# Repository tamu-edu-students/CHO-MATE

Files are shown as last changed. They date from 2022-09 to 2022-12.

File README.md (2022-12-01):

<p align="center">
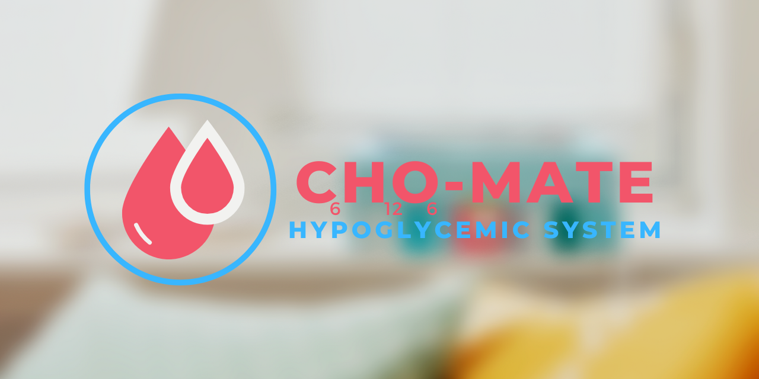
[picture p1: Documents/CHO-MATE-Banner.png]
  
</p>

# CHO-MATE

This is the CHO-MATE Hypoglycemic Center Project for ECEN 403 and ECEN 404 at Texas A&M University.

## The Problem
In the U.S. Alone over 10% of the population suffers from Diabetes. Type 1 diabetes can require a person to monitor their blood sugar level 4-10 times a day and intake carbohydrates if their blood sugar is low. This can become a guess and check game where the person is not able to consistently and accurately dose themselves, and can lead to detrimental effects on quality of life.

## Our Solution
Our device shall be a tool for those who suffer from Hypoglycemia in order to take preventative action to dose the user when their blood sugar begins to drop below acceptable conditions. We hope to provide a smooth running and adaptive source of accurate sugar dispensing to our consumers. Accomplishing both a maintenance efficient and emergency equipped system to ease some of the stress that the user must deal with on a day to day basis.

## Application Setup
To setup your own version of the application, download the [Expo Go](https://expo.dev/client) on your phone application to get started.

1. Clone the repo to your computer - `git clone https://tamu-edu-students/CHO-MATE.git`
2. Ensure NodeJS is installed on your system - You can download NodeJS [here](https://nodejs.org/en/download/)
3. Run `npm install` in the Application directory
4. Run `npm run dev` to start a development server, and **scan the QR code using your phone**. This will open Expo Go.
5. You're all set!

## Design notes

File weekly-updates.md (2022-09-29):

# CHO-MATE-Updates
## 9/29/2022
**Holden (Power Supply)** - Power Supply: Finalized validation, Began housing design in cad, Integrated with microcontroller to check everything works,
**Kelton (Application)** - Working on notification testing, adding more app screens for more user information
**Abhi (Microcontroller)** - Started CAD Design, measuring each component for input into AutoCAD

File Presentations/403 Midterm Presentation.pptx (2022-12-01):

## Team members: Kelton Chesshire, Holden Haile, Abhi Singh Sponsor: Skyelar Head TA: Sambandh Dhal


Hypoglycemic Center - C6H12O6-MATE

## Project Description - Background

In the U.S. Alone over 10% of the population suffers from Diabetes. This group has been the inspiration for many devices that make checking blood sugar simple and consistent, but none to help maintain their daily glucose intake.

## Project Description - Solution Proposal

Develop a device that can accurately dispense carbohydrates in a consistent and easily-consumable manner so that users can accurately manage their glucose levels.

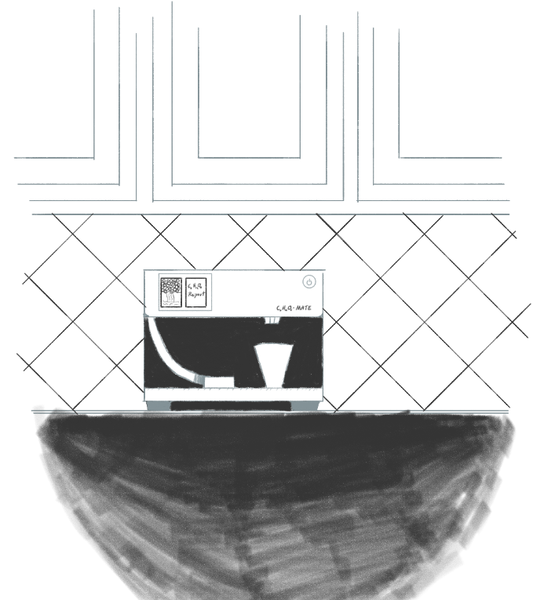
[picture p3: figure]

## Flow Chart of Subsystems

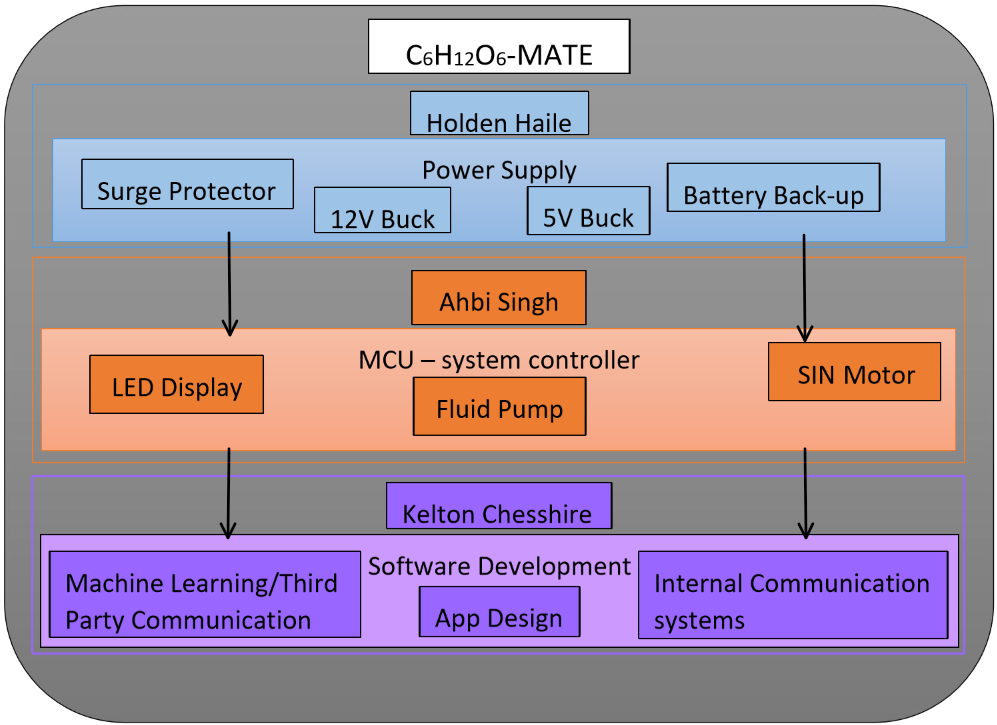
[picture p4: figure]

## Power Supply: Holden Haile

- Consists of:
  - 2 Buck converters
    - 1 x (12V, 4W) to 1 output
    - 1 x (5V, 7.5W) to 3 outputs
  - Surge Protector
  - Battery Backup

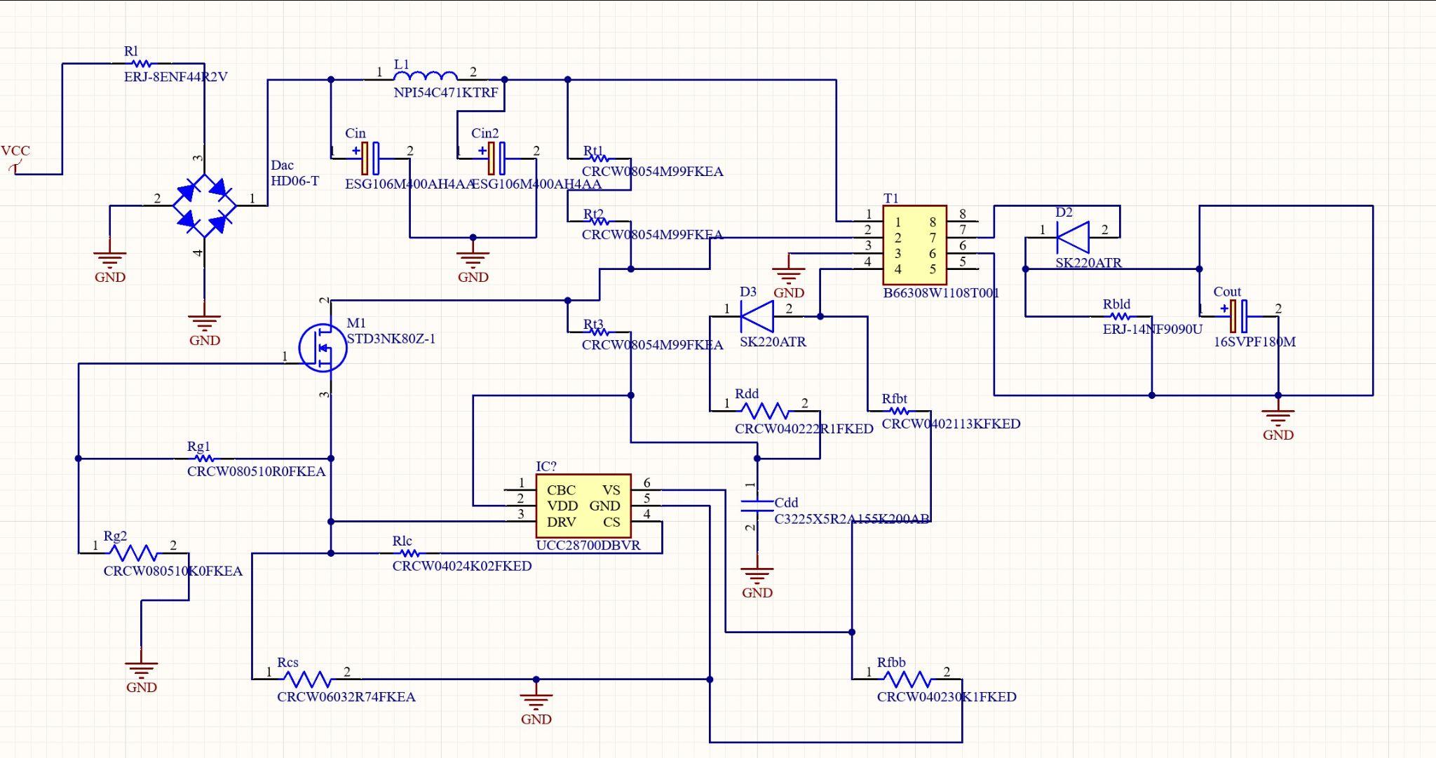
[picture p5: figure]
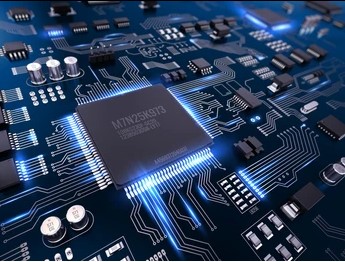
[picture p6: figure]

Image from Shudderstock.com

## Dispensing System & MCU: Abhi Singh

- Dispensing System
  - Skittle Dispenser
  - Juice Dispenser
- Onboard User Interface
  - Touch Screen Display
  - Communicates with MCU
- MCU
  - Connected via WiFi/Bluetooth to our backend which enables us to automatically dispense and alert.

## Application & Machine Learning: Kelton Chesshire

- Consists of:
  - Application Frontend & UI Design
    - Expo/Native React
  - Application Backend
    - Firebase & Express.js
  - Communication Protocols
    - WiFi Communication
    - Bluetooth Communication
  - Machine Learning

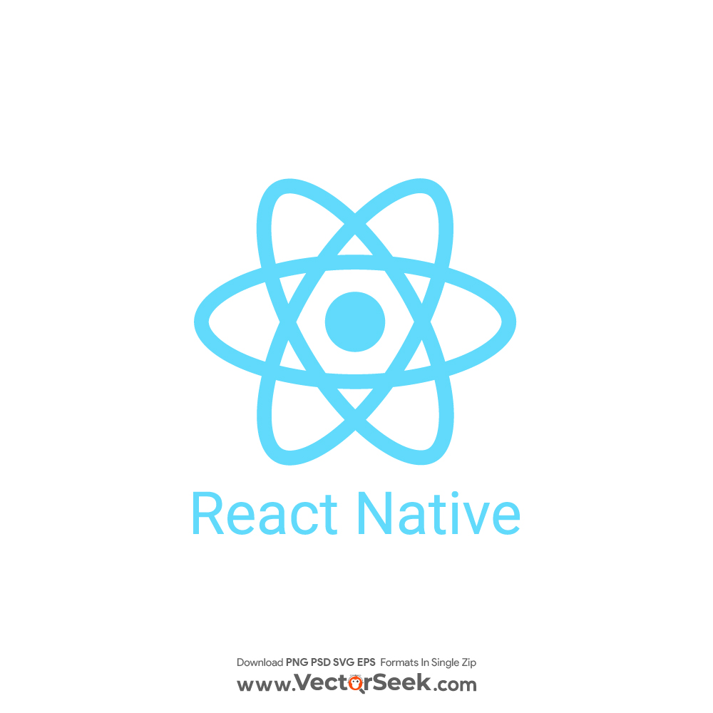
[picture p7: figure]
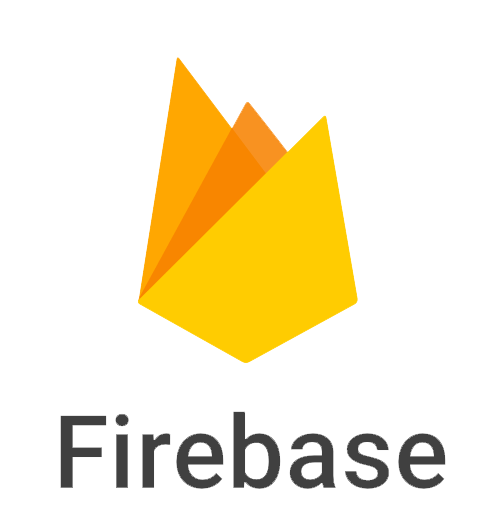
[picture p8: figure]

## Execution plan

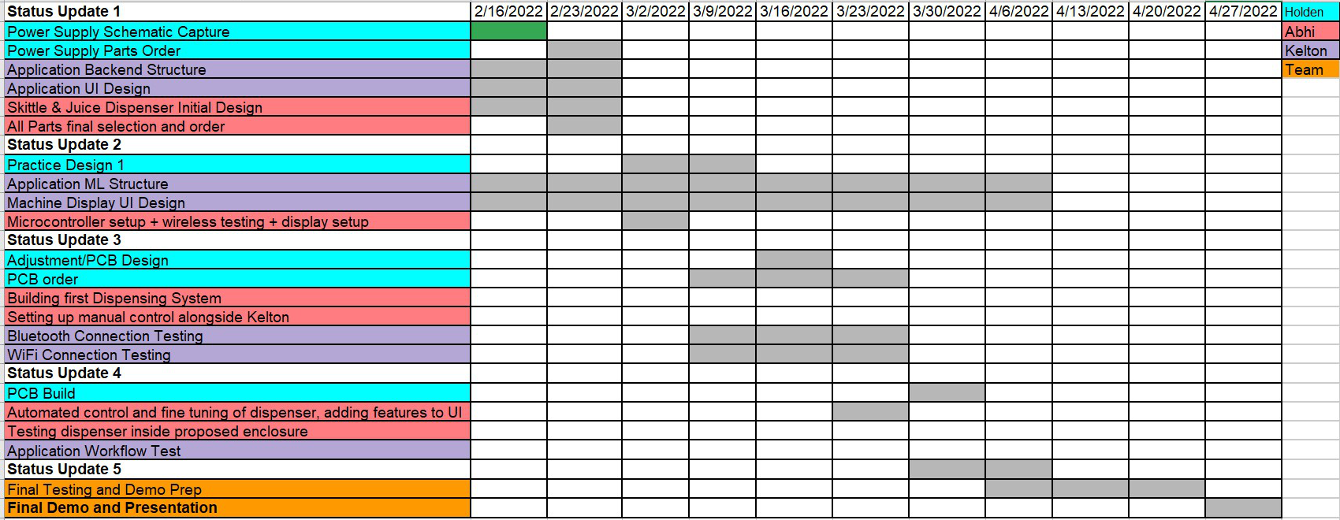
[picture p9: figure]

## Validation plan

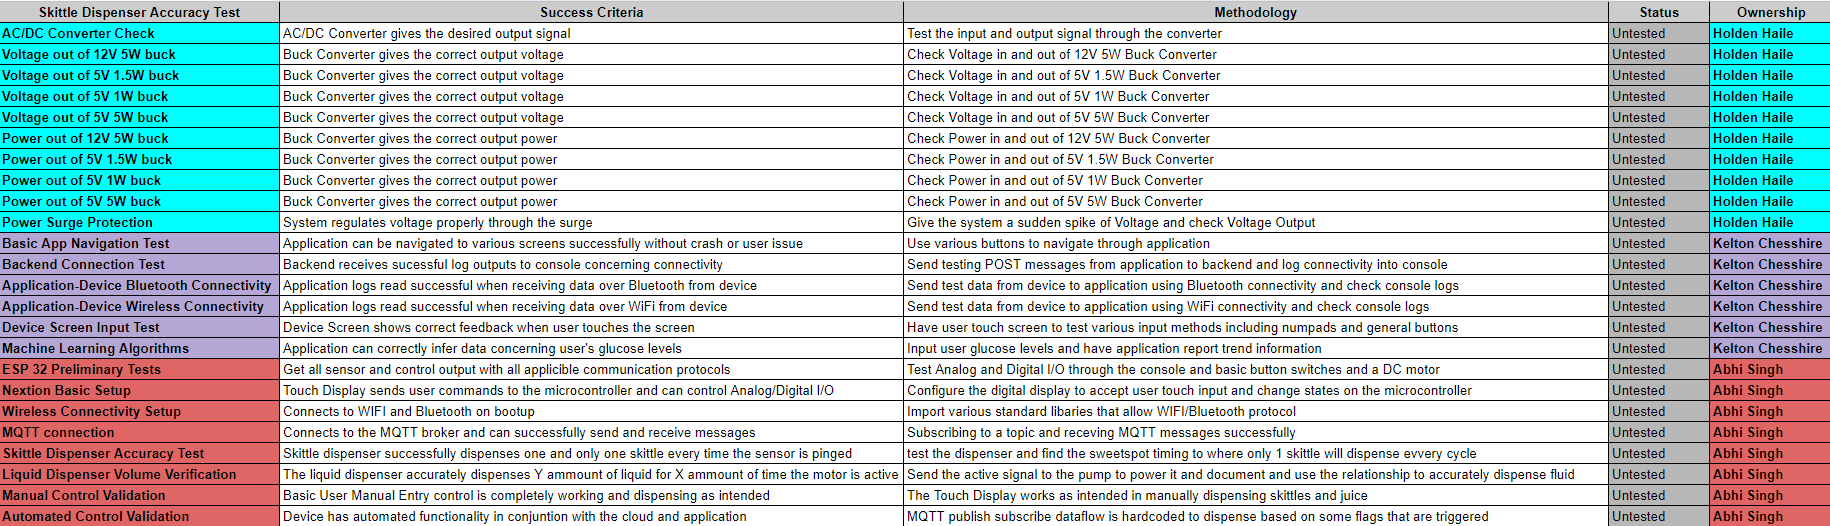
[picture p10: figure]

## Part order status

part description | Status (order approved/order placed/part received)
Raspberry Pi x 2 | Part Received
Arduino Nano | Part Received
Test Phone | Part Received
Peristaltic Liquid Pump | Not Ordered Yet

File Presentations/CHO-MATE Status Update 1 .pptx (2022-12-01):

## Bi-Weekly Update 1 Team 32: Abhi Singh, Holden Haile, Kelton Chesshire Sponsor: Skyelar Head TA: Eric Lloyd Robles


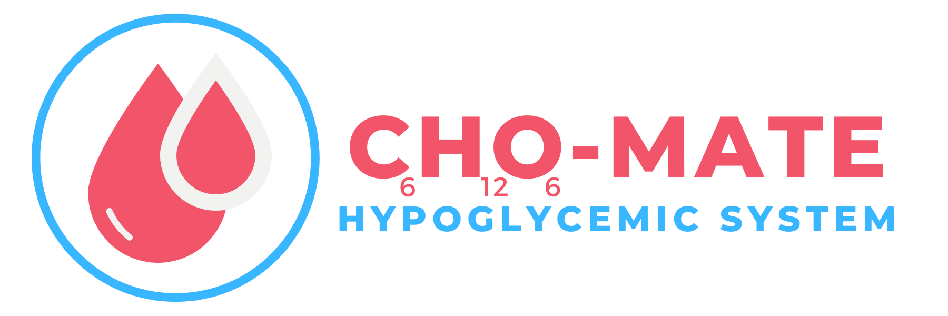
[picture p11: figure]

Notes: Michelle

## Problem Statement

In the U.S. Alone over 10% of the population suffers from Diabetes. Type 1 diabetes can require a person to monitor their blood sugar level 4-10 times a day and intake carbohydrates if their blood sugar is low. This can become a guess and check game where the person is not able to consistently and accurately dose themselves, and can lead to detrimental effects on quality of life.

## Solution Proposal

Our system will dispense carbohydrates in a consistent, accurate, and easily-consumable manner so that users have an easy way of maintaining a normal blood sugar level 24/7.


## System Overview

Power Supply

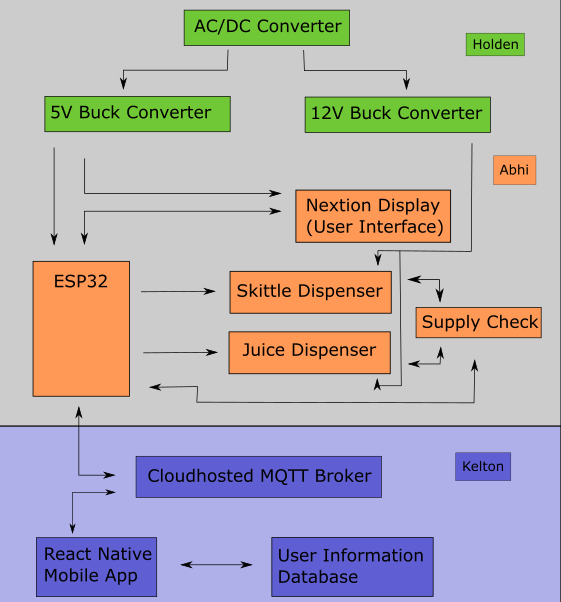
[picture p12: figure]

Dispenser

Application

## Subsystem Changes/Improvements for 404

Design Changes proposed to us by Dr. John Lusher and Subsystem Improvements that are being added for 404
Dispenser: Implementing the Skittle & Juice Stock Checker for our Dispenser, improving switching design of the dispenser, implement Nextion display
Power Supply: Swapping Voltage Regulators out and Downsizing Capacitors on Power Supply
Application: Status notifications, Glucose input, integration with Apple HealthKit and Google Fit

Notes: Eric

## Project Timeline

Discuss System Improvements

We focused on how to improve our subsystems from the good baseline from 403

Last Week

Next 2 weeks

Subsystem Improvements

Subsystem Improvements will be made and tested

10/5

Major Project Design

Design Housing and PCBs for Power Supply and Dispenser, App integration with Health Apps, HMI control implemented

11/5

Final Subsystem Integration

Dispenser and Power Supply will be installed in the housing, testing and validation of System: Dispenser powered with our Power Supply and Tested with Our App

11/16

Preparation for Final Presentation & Demo

Final Tweaks to subsystems if needed, polishing the product for presentation and testing user experience

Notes: Eric

## Power Supply Holden Haile

Accomplishments since 403 15 hrs of effort | Ongoing progress/problems and plans until the next presentation
Buck converters integrated with the MCU Discussed issues with Dr. Lusher | Implementation of re-design suggestions from Dr. Lusher Begin PCB design Begin housing design

## Power Supply Holden Haile

- 5V buck - working
- 12V buck - not providing enough power to operate at the speeds that we would like
- Revised buck design below

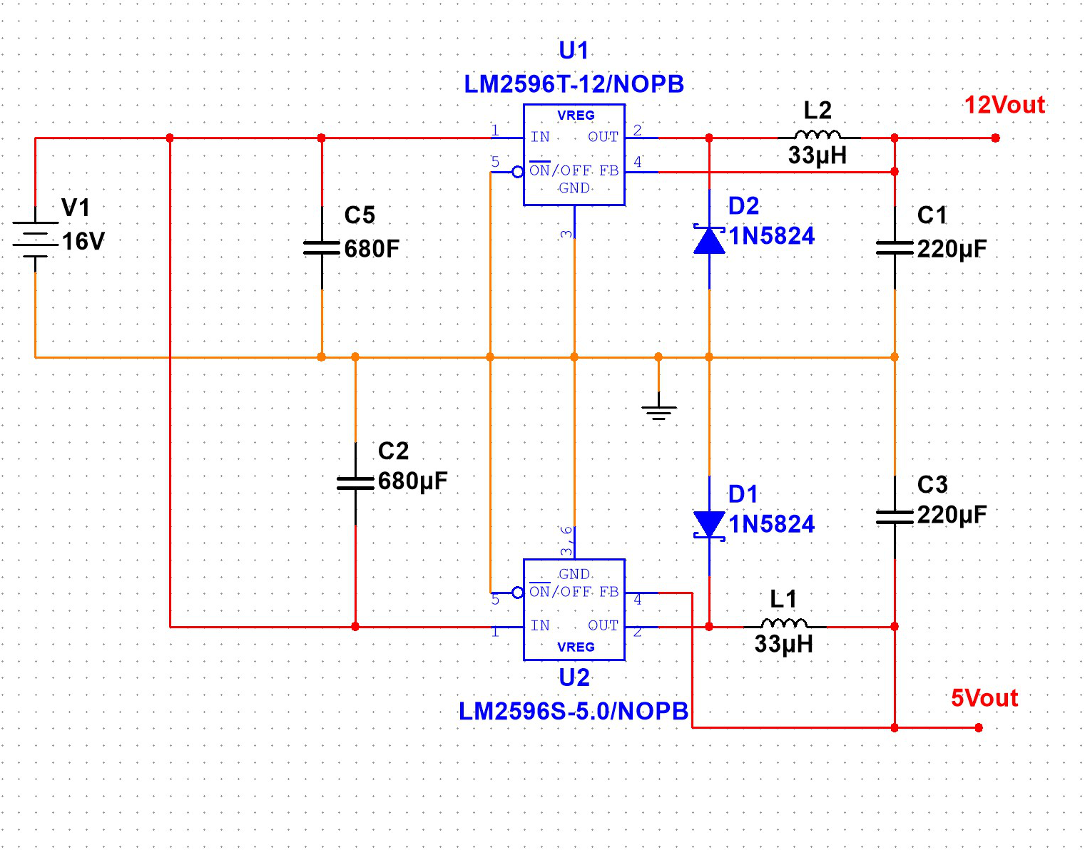
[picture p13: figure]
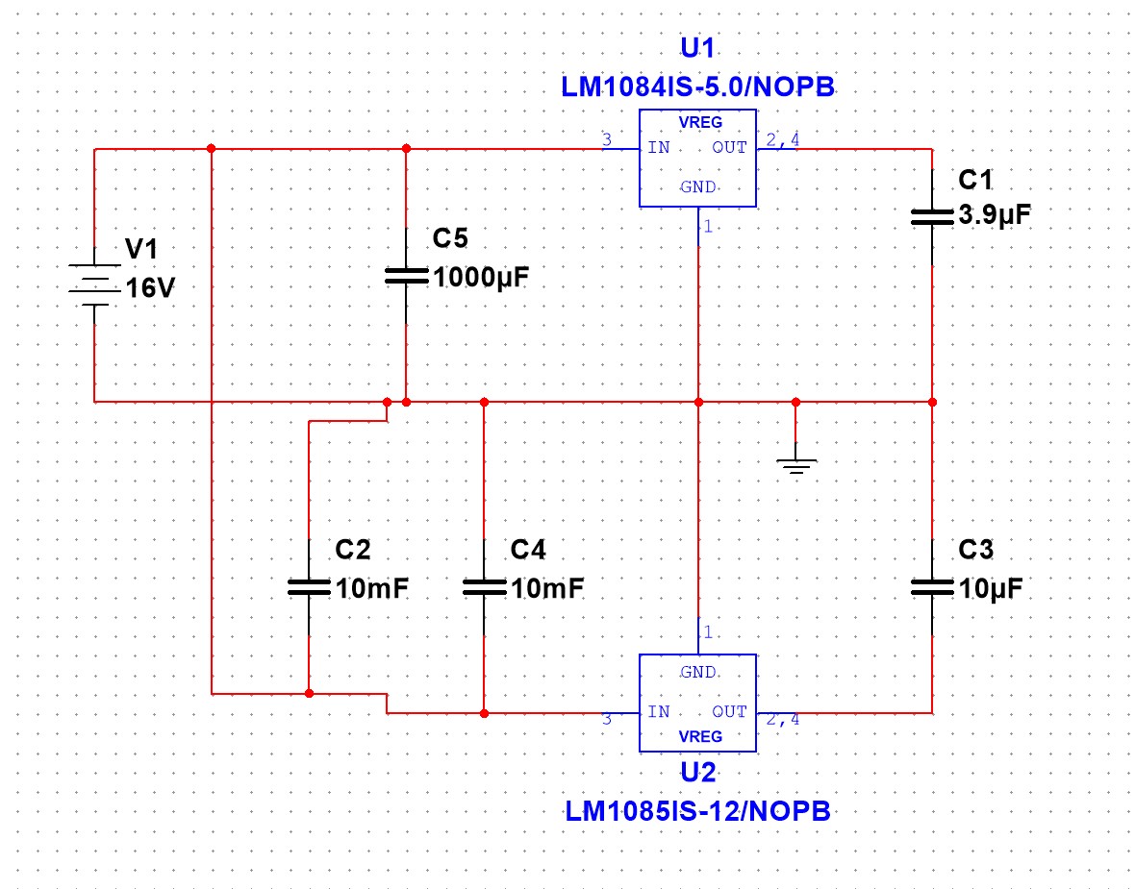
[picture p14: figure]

## Dispenser Abhi Singh

Accomplishments since 403 5 hrs of effort | Ongoing progress/problems and plans until the next presentation
Research and Sourced Sensors for Stock Checker Designed improved circuitry for dispenser using CMOS transistors instead of HV Relays | Test Ultrasonic and Pressure sensors with ESP32 Test MOSFET circuit on breadboard Implement Nextion Display (HMI)

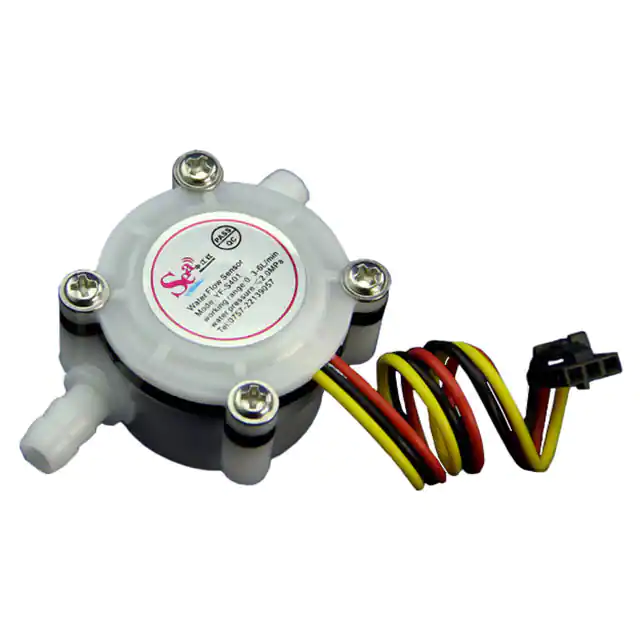
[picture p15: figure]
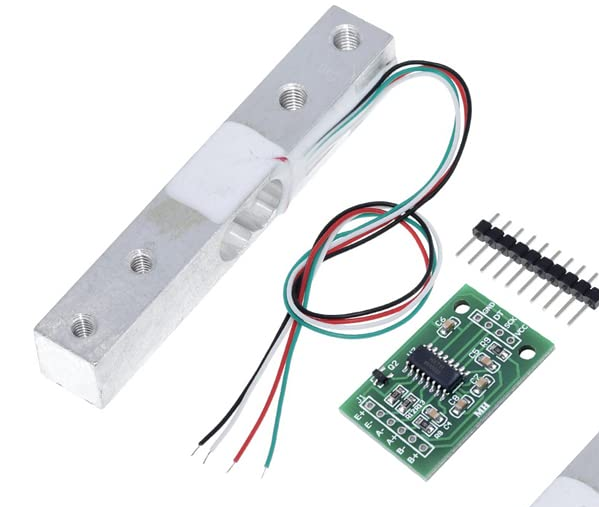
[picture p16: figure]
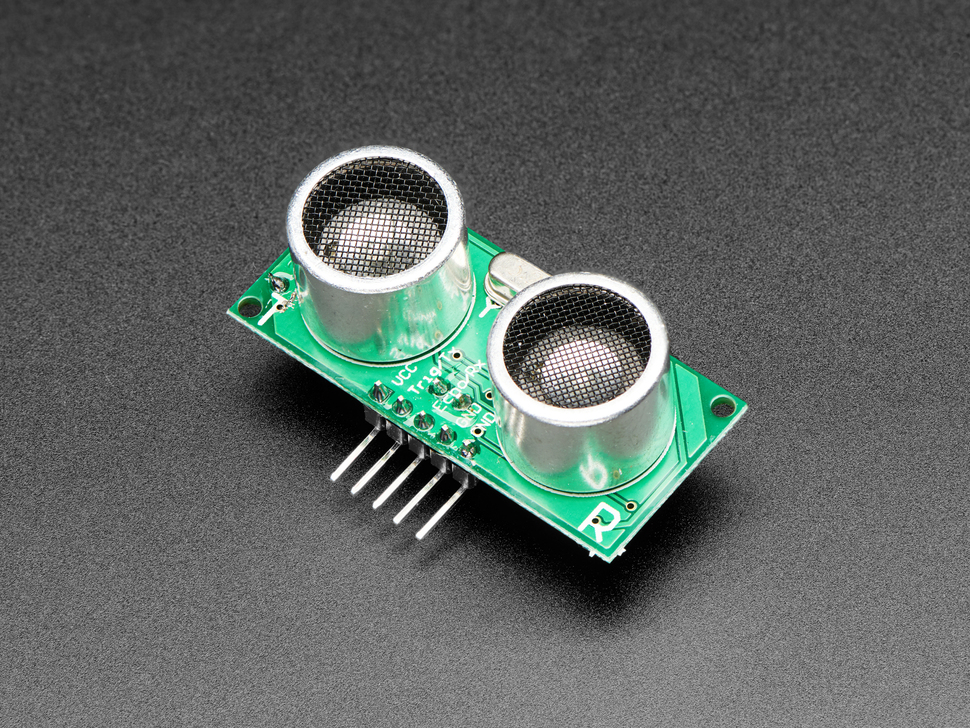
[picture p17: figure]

## Dispenser Abhi Singh

- N Channel MOSFET on the low side of the load (pump & solenoid)
- Components are here, just have to test the circuit for proof of concept
- Better alternative to what we used last semester (HV relay Optocoupler)

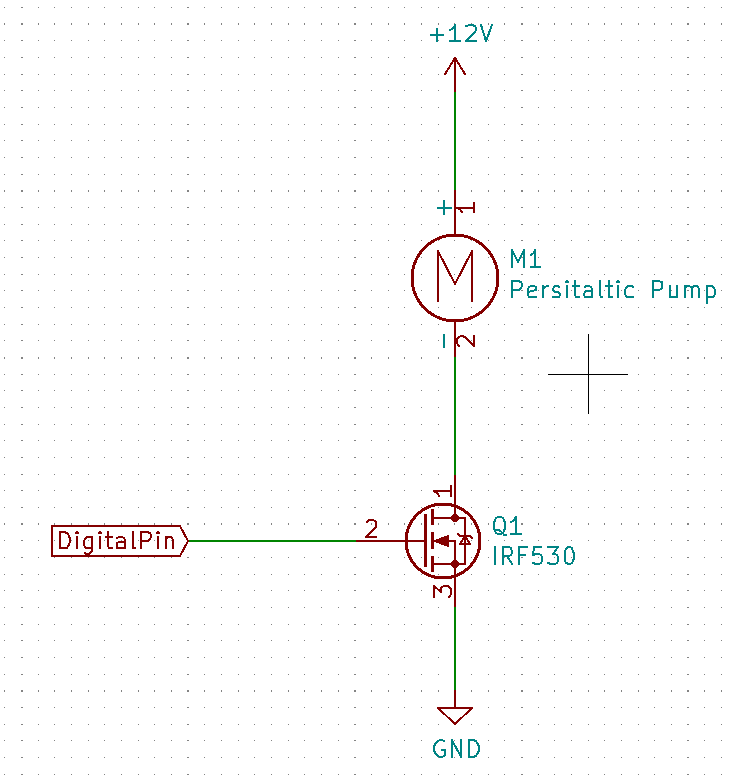
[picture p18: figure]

## Application Kelton Chesshire

Accomplishments since 403 12 hrs of effort | Ongoing progress/problems and plans until the next presentation
MQTT Communication w/ Dispenser Google Firestore Database Firebase Authentication Basic Dispense Function Previous Dispensings Screen | Dispenser Notifications Glucose Input BMI Information Work on Nextion Display with Abhi

## Application Kelton Chesshire

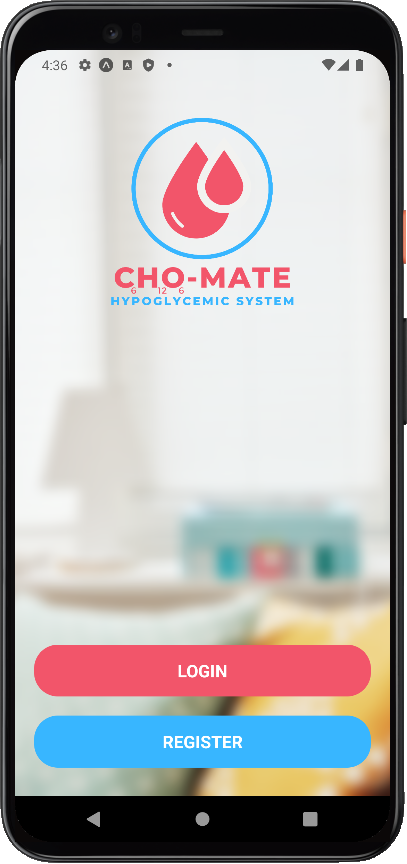
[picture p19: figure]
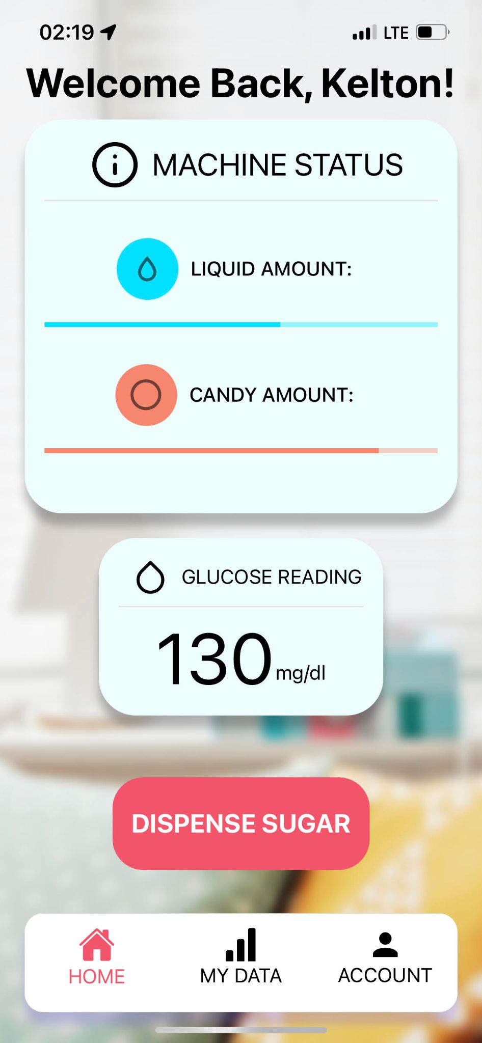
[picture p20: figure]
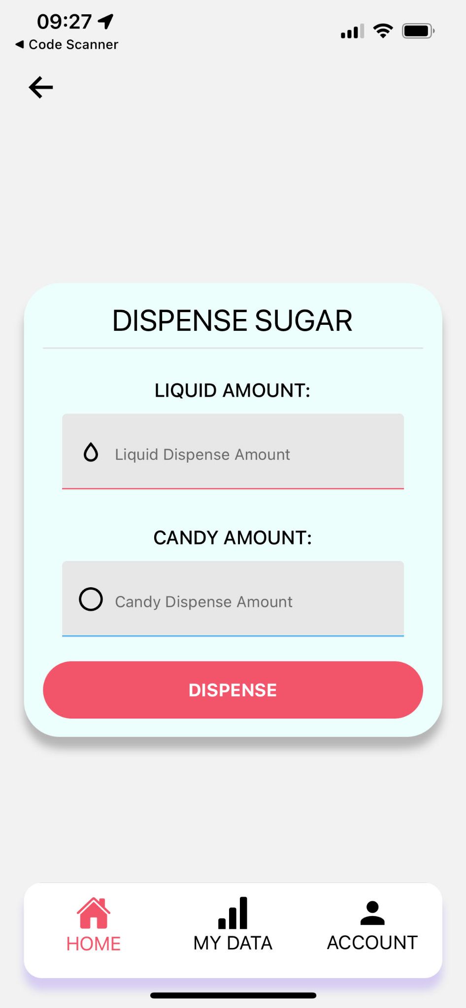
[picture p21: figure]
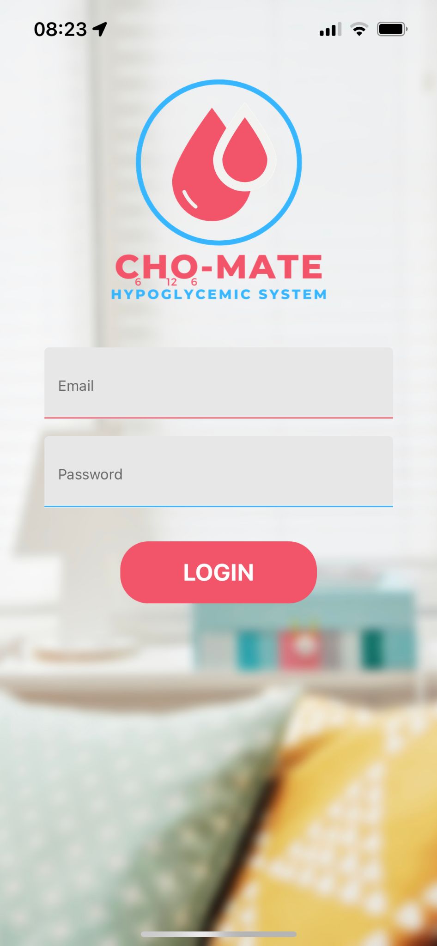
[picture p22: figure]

## Validation Plan

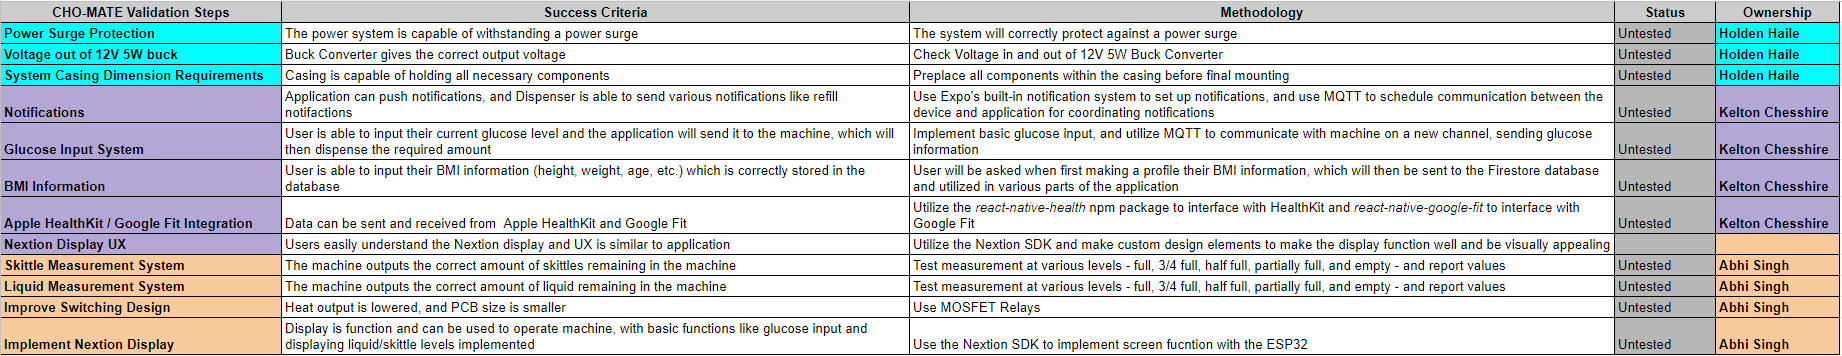
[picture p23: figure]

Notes: Michelle

## Execution Plan

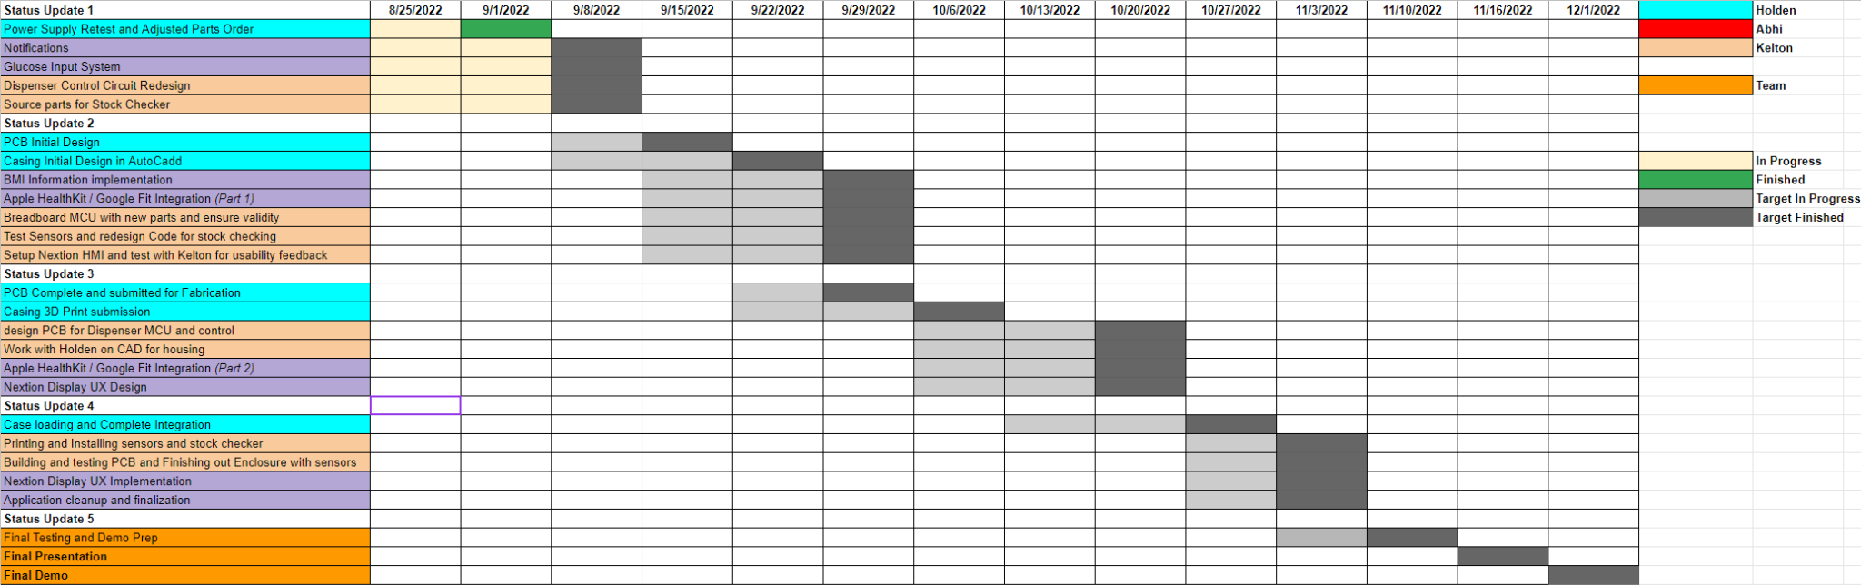
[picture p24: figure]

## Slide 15

Questions?

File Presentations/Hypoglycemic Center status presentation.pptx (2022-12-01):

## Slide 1

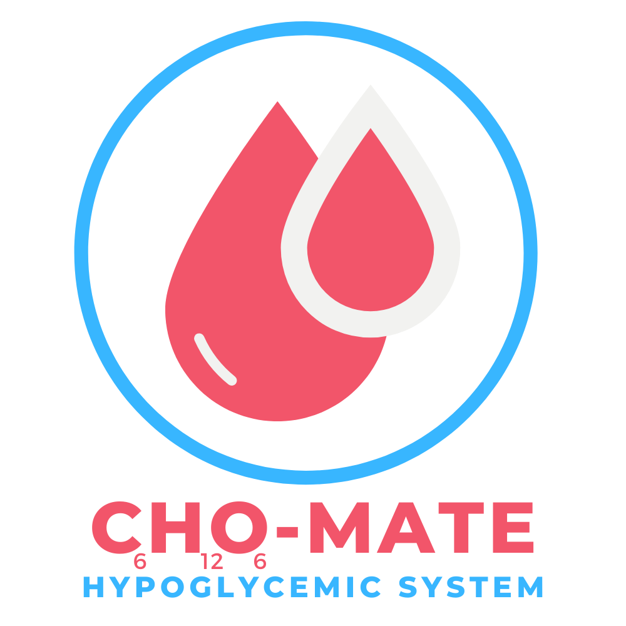
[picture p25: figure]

Sponsor:
Skyelar Head
Professor:
Dr. Kevin Nowka

Team members:
Kelton Chesshire
Holden Haile
Abhi Singh
Teaching Assistant: Sambandh Dhal

## Project Description - Background

In the U.S. Alone over 10% of the population suffers from Diabetes. This group has been the inspiration for many devices that make checking blood sugar simple and consistent, but none to help maintain their daily glucose intake.

## Project Description - Solution Proposal

Develop a device that can dispense carbs
- consistently
- accurately
- easily-consumable manner so that users can accurately manage their glucose levels.


## Flow Chart of Subsystems


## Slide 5

Power Supply Status | Buck Converter Schematic Design | Buck converter parts order | Proto Board construction | Proto Board testing | PCB Design

Microcontroller Status | Dispenser Proof of Concept & Barebones Networking | MQTT Broker setup & Testing with Dispenser | Nextion Display Interface setup | Dispenser Housing & Dispensing Accuracy | Stock Level check & MQTT multi topic messages

Software Status | Application UI Development | Application Authentication Backend

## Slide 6

Power Supply Holden Haile

Finalized Design of Both Buck Converters - 17 Hrs | Ongoing progress/problems and plans until the next presentation
adjusted designs to accommodate changes in hardware finalized designs and produced schematics ordered parts for prototype board | Awaiting parts ordered (end of week) Beginning design of PCB Practice soldering using parts ordered



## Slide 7

Dispensing System Abhi Singh

Dispenser Proof of Concept & WiFi 10 hrs | Ongoing progress/problems and plans until the next presentation
Peristaltic pump PWM testing with arduino nano and L298N motor controller esp32 network connection (Wi-Fi) achieved | setting up MQTT broker and testing dispense commands skittle dispenser test with actuator Dispenser housing design in SolidWorks


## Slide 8

Mobile Application Kelton Chesshire

Accomplishments since the last presentation 14 hrs | Ongoing progress/problems and plans until the next presentation
Basic Application UI Library UI screens Application Form Validation and Authentication | Further backend development Connection between application and Raspberry Pi testing system using MQTT Glucometer connection Push Notifications


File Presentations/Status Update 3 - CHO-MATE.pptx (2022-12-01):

## Bi-Weekly Update 3 Team 32: Abhi Singh, Holden Haile, Kelton Chesshire Sponsor: Eric Lloyd Robles TA: Eric Lloyd Robles



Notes: Michelle

## Problem Statement

In the U.S. Alone over 10% of the population suffers from Diabetes. Type 1 diabetes can require a person to monitor their blood sugar level 4-10 times a day and intake carbohydrates if their blood sugar is low. This can become a guess and check game where the person is not able to consistently and accurately dose themselves, and can lead to detrimental effects on quality of life.

## Solution Proposal

Our system will dispense carbohydrates in a consistent, accurate, and easily-consumable manner so that users have an easy way of maintaining a normal blood sugar level 24/7.


## System Overview

Power Supply


Dispenser

Application

## Subsystem Changes/Improvements since last week

Design Changes proposed to us by Dr. John Lusher and Subsystem Improvements that are being actively implemented
Dispenser: Tested Sensors, Planned Circuit Layout, Measured Dimensions for the enclosure CAD model
Power Supply: Completed system validation and verified all values in and out of the circuit
Application: Further Notification / Background Task Testing

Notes: Eric

## Project Timeline

Discuss System Improvements

We focused on how to improve our subsystems from the good baseline from 403

Last Week

Next 2 weeks

Subsystem Improvements

Subsystem Improvements will be made and tested

10/5

Major Project Design

Design Housing and PCBs for Power Supply and Dispenser, App integration with Health Apps, HMI control implemented

11/5

Final Subsystem Integration

Dispenser and Power Supply will be installed in the housing, testing and validation of System: Dispenser powered with our Power Supply and Tested with Our App

11/16

Preparation for Final Presentation & Demo

Final Tweaks to subsystems if needed, polishing the product for presentation and testing user experience

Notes: Eric

## Power Supply Holden Haile

Accomplishments since last presentation 8 hrs of effort | Ongoing progress/problems and plans until the next presentation
Validation finalized Began crash course on CAD modeling to begin enclosure design | Housing Design process Complete integration of microcontroller and power supply system

## Power Supply Holden Haile

- Power supply Validated and prepared for integration
- Housing design process started and will be worked on in the next two weeks


## Dispenser Abhi Singh

Accomplishments since Last Update 6 hrs | Ongoing progress/problems and plans until the next presentation
Designed an updated dispenser that incorporates the pressure sensor cell and improves the design to get rid of skittle jams | Design the lid for the Juice volume measurer (ultrasonic sensor 3D print both designs and begin validation Design Nextion Display pages for User Interface and test with ESP32


## Dispenser Abhi Singh


- Updated dispenser now uses a Pressure Load Cell to measure current amount of Skittles
Next Step:
- design the enclosure that will house the dispenser and the juice canister
- design the lid that will read the amount of juice in the canister

## Application Kelton Chesshire

Accomplishments since Last Update 12 hrs of effort | Ongoing progress/problems and plans until the next presentation
Notification Testing Background Task Testing | Further Notification & Background Task Testing More Information Screens

## Application Kelton Chesshire


## Validation Plan


## Execution Plan


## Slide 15

Questions?

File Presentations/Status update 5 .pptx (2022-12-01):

## Bi-Weekly Update 5 Team 32: Abhi Singh, Holden Haile, Kelton Chesshire Sponsor: Eric Lloyd Robles TA: Eric Lloyd Robles



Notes: Michelle

## Problem Statement

- In the U.S. Alone over 10% of the population suffers from Diabetes.
- Type 1 diabetes requires monitoring of blood sugar levels 4-10 times a day.
- The process can become a guess and check game with inconsistent data and little comfort for the user.


## Solution Proposal

- Dispense carbohydrates in a consistent, accurate, and easily-consumable manner.
- Provide the user with information regarding their personal blood sugar patterns.


## System Overview


Power Supply

Dispenser

Application

## Project Timeline

Discuss System Improvements

We focused on how to improve our subsystems from the good baseline from 403

Check point 1

Check point 2

Subsystem Improvements

Subsystem Improvements will be made and tested

Check point 3

Major Project Design

Design Housing and PCBs for Dispenser, App integration with Health Apps, HMI control implemented

Check point 4

Final Subsystem Integration

Dispenser and Power Supply will be installed in the housing, testing and validation of System: Dispenser powered with our Power Supply and Tested with Our App

Final Product

Preparation for Final Presentation & Demo

Final Tweaks to subsystems if needed, polishing the product for presentation and testing user experience

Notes: Eric

## Housing Design Holden Haile

Accomplishments since last presentation 17 hrs of effort | Ongoing progress/problems and plans until the next presentation
Learned the basics of solidworks from Ahbi Created first iteration of housing in solidworks | Final adjustments before submitting for 3D print

## Housing Design Holden Haile

- Housing design in cooperation with Abhi
- Housing will hold:
  - Juice & Skittle Dispensers
  - Power Supply & Surge Protector
  - Front Facing Nextion Display
  - Dispensing Tray


## Beginning Vision vs Housing Design


## Housing Design


## Dispenser Abhi Singh

Accomplishments since Last Update 7 hrs | Ongoing progress/problems and plans until the next presentation
Finished designing the PCB and validated the traces alongside the breadboarded circuit Ordered the PCB Helped Holden with the dispenser housing dimensions | Design Nextion Display pages for user interface using Kelton’s Canva Designs and test with ESP32 Build the dispenser using completed 3D prints and our various electronic components

## Dispenser Abhi Singh

- PCB is designed, reviewed, and ordered
- Currently running prints for completed CAD parts


## Application Kelton Chesshire

Accomplishments since Last Update 9 hrs of effort | Ongoing progress/problems and plans until the next presentation
Backend deployment and setup Notification Service deployment | More information screens Nextion Display UI

## Application Kelton Chesshire

BACKEND:
Sends “STOCK” through MQTT to all CHO-MATE devices

CHO-MATE:
Sends back Liquid and Skittle amounts

BACKEND:
If below 20%, send low notification to Application


## Validation Plan


## Execution Plan


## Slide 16

Questions?

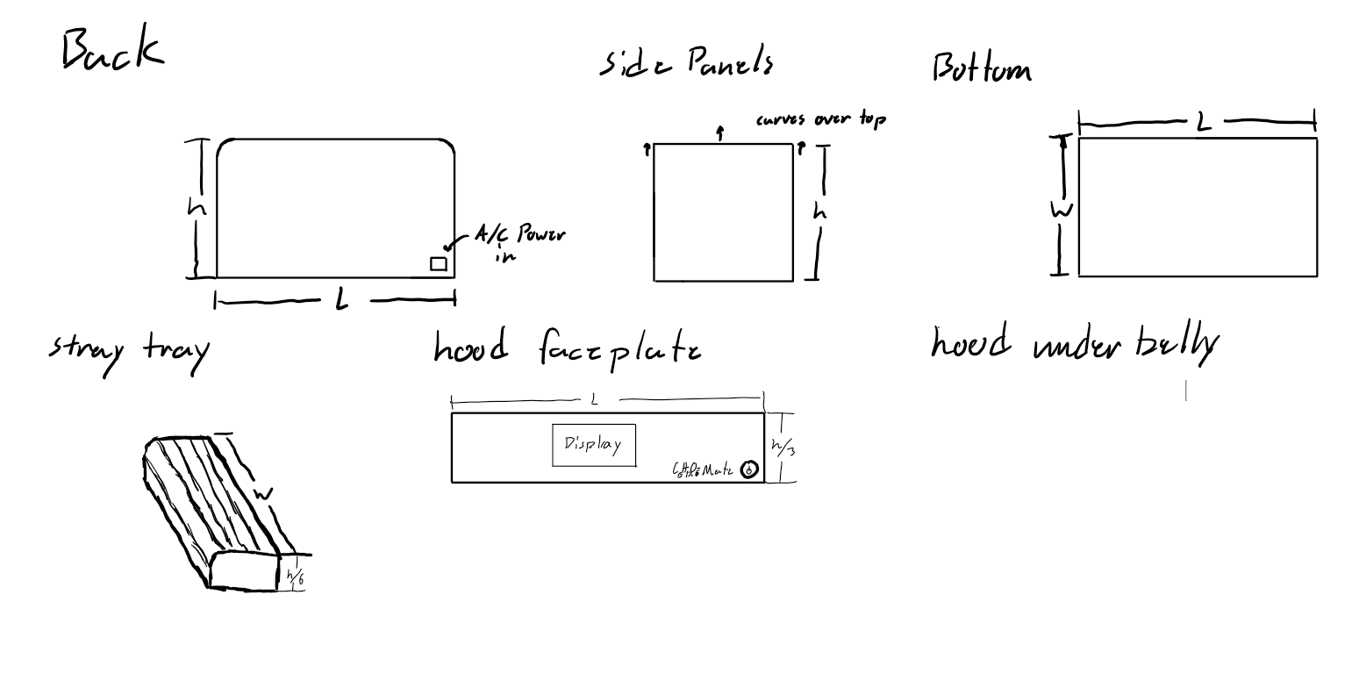
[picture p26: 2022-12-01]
Documents/Housing sketches.png

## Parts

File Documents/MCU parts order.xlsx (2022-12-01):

Part Name | Link | Unit Price | Quantity | Team Member | Order Status | Net Cost
ESP32 | https://www.amazon.com/gp/product/B0718T232Z/ref=ox_sc_act_title_3?smid=A30QSGOJR8LMXA&psc=1 | $10.99 | 1 | Abhi | Sent to Business Office | $11
Peristaltic Pump | https://www.amazon.com/gp/product/B09MS6C91D/ref=ox_sc_act_title_1?smid=A13IDDRW9YEST&psc=1 | $31 | 1 | Abhi | Sent to Business Office | $31
Nextion 5'' Enhanced | https://itead.cc/product/nx8048k050-nextion-5-0-enhanced-series-hmi-touch-display/ | $69.90 | 1 | Abhi | Sent to Business Office | $69.90 | Total
L298N motor controller | https://www.amazon.com/Qunqi-Controller-Module-Stepper-Arduino/dp/B014KMHSW6 | $6.99 | 1 | Abhi | Sent to Business Office | 6.99 | 118.89
404 Parts
flow meter | https://www.digikey.com/en/products/detail/seeed-technology-co.,-ltd/314150001/5488169 | $9.50 | 1 | Abhi | sent
weight sensor | https://www.amazon.com/Digital-Weighing-Arduino-Portable-Electronic/dp/B09K7G3477?s=industrial | 8 | 2 | Abhi | sent
ultrasonic sensor | https://www.adafruit.com/product/4019 | 6.95 | 1 | Abhi | sent

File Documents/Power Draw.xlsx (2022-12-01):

Component | Link | Voltage (Volts) | Needs Regulation? (Y/N) | Max Rated Power Draw (Watts) | current
12V supply
Peristaltic Pump | https://www.adafruit.com/product/1150#technical-details | 12V | Y | 24W | 2A
10mm P+P Solenoid | https://www.amazon.com/Kiro-Seeu-JF-0530B-Electromagnet-Keepping/dp/B09B2772PX | 12V | Y | 7.2W | 0.6
 |  |  |  |  | total current
 |  |  | 12V Power Draw Max | 31.2W | 2.6A
5V supply
ESP32 | https://www.amazon.com/gp/product/B0718T232Z/ref=ox_sc_act_title_3?smid=A30QSGOJR8LMXA&psc=1 | 5V | Y | 1.5W | .3A
Nextion Display 5'' | https://itead.cc/product/nx8048k050-nextion-5-0-enhanced-series-hmi-touch-display/ | 5V | Y | 5W | 0.41A
N channel MOSFETS | https://www.amazon.com/HiLetgo-Channel-optocoupler-Support-Trigger/dp/B00LW15A4W | 5V | Y | 1W
 |  |  |  |  | total current
 |  |  | 5V Power Draw Max | 7.5W | 1.5A

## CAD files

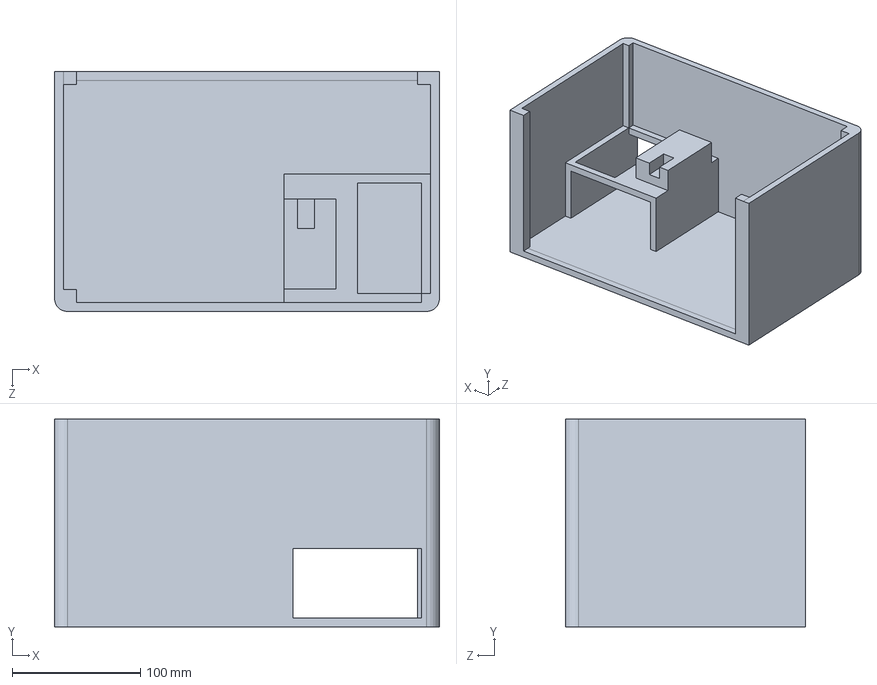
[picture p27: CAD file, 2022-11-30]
SolidWorks/Back_updated_full.SLDPRT
300.0 x 162.0 x 187.0 mm

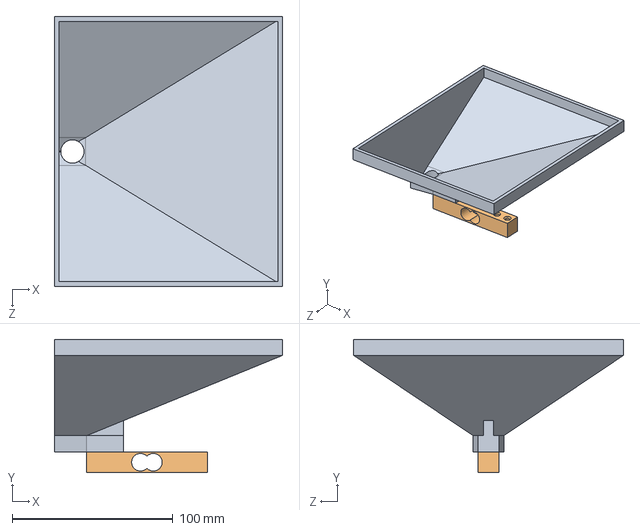
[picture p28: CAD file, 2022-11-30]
SolidWorks/skittledispenser.SLDASM
142.0 x 83.0 x 168.0 mm
updated_funnel
pressure_sensor

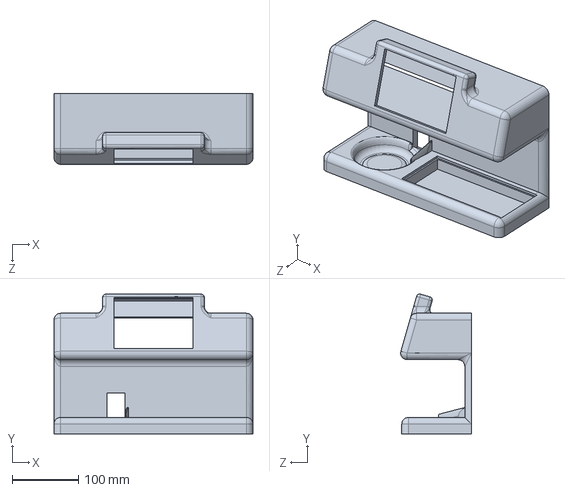
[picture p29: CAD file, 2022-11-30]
SolidWorks/Assem1.SLDASM
300.0 x 210.9 x 106.7 mm

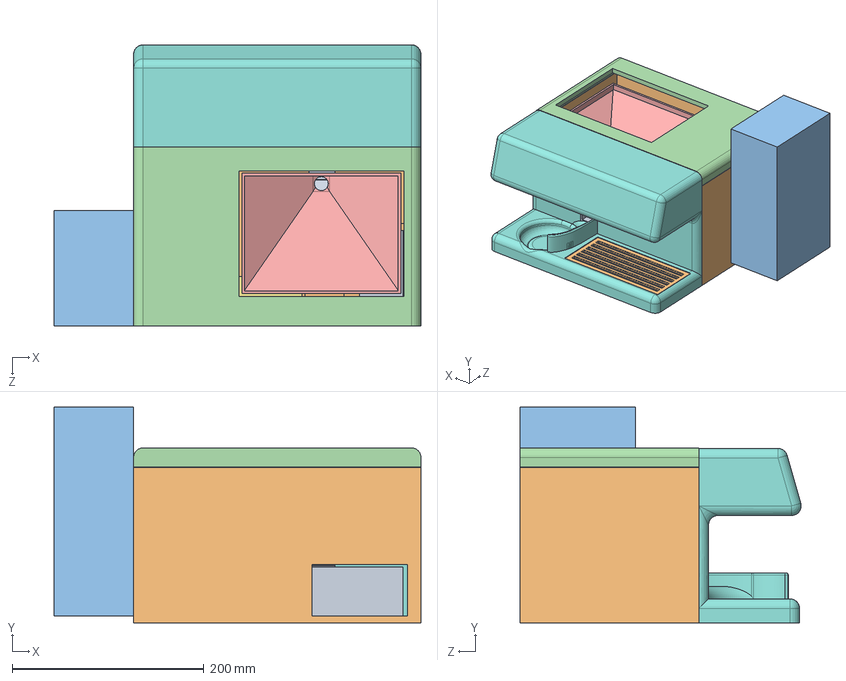
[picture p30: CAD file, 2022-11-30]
SolidWorks/Assembly.SLDASM
383.0 x 225.0 x 293.7 mm
Surge Protector
Back_updated
Water bottle
Top
updated_funnel
pressure_sensor
psu
Tray
Skittle Ramp
Tray insert

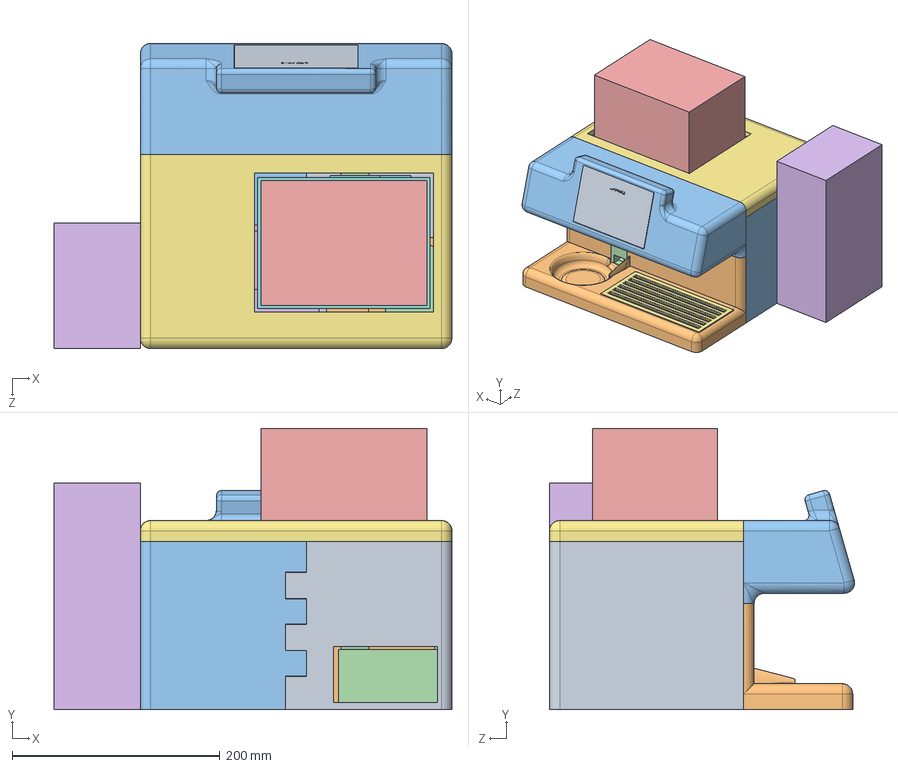
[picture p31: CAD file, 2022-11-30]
SolidWorks/V1_Final_Assembly.SLDASM
383.0 x 270.7 x 293.7 mm
Back_updated_left
power_supply_housing
back_updated_right
Surge Protector
pressure_sensor
psu
Top
dispenserv3
Nextion 5inch display
Tray_bottom
Tray_Top
Skittle ramp version 2
Skittle_container
Water bottle
Tray insert

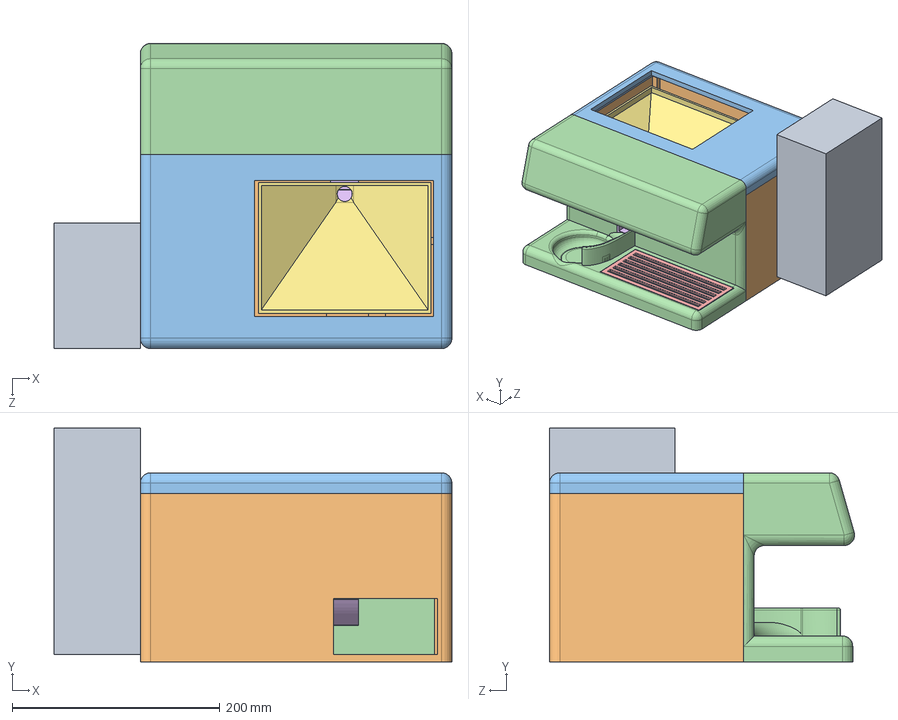
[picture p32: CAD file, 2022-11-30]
SolidWorks/Assem remake.SLDASM
383.0 x 225.0 x 293.7 mm
Back_updated
Top
Tray
Tray insert
Skittle Ramp
Water bottle
updated_funnel
pressure_sensor

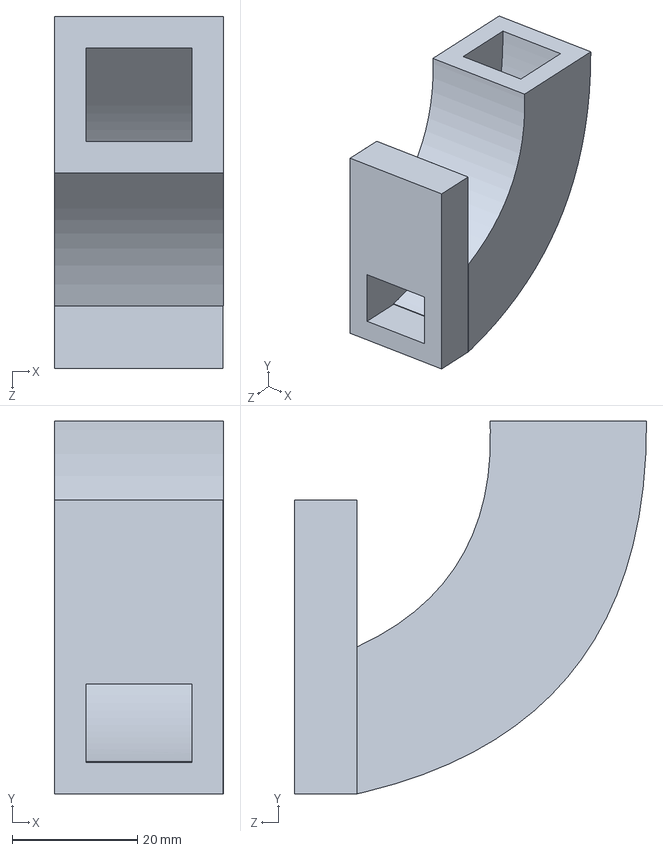
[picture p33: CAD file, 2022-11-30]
SolidWorks/Skittle ramp version 2.SLDPRT
27.0 x 59.5 x 56.2 mm

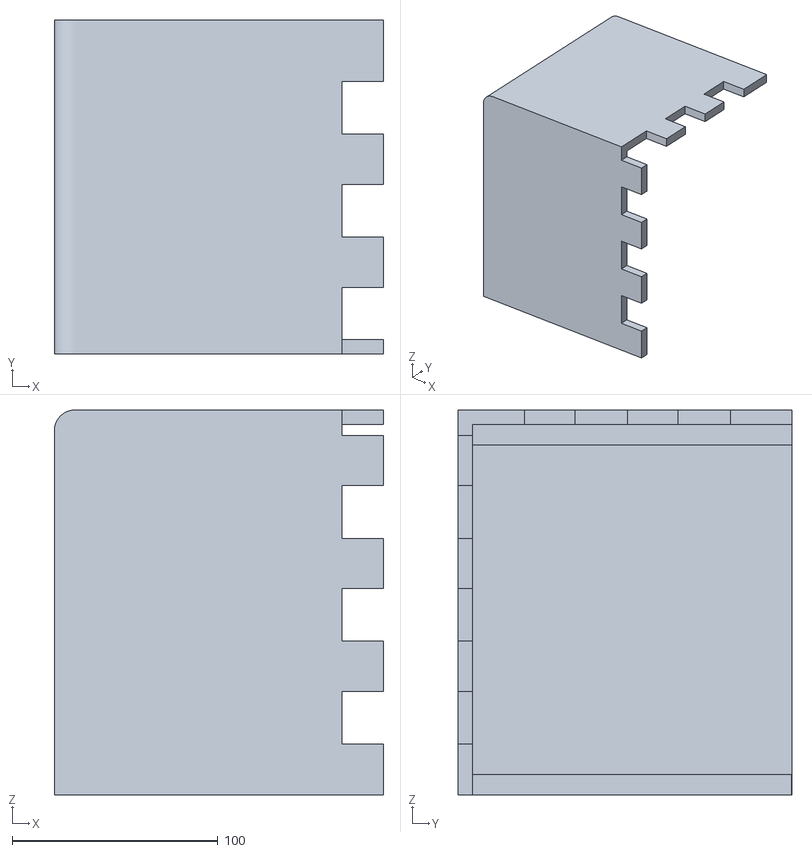
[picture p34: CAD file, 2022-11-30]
STL files/Housing_Right_Juice_Side.STL
160.0 x 162.0 x 187.0

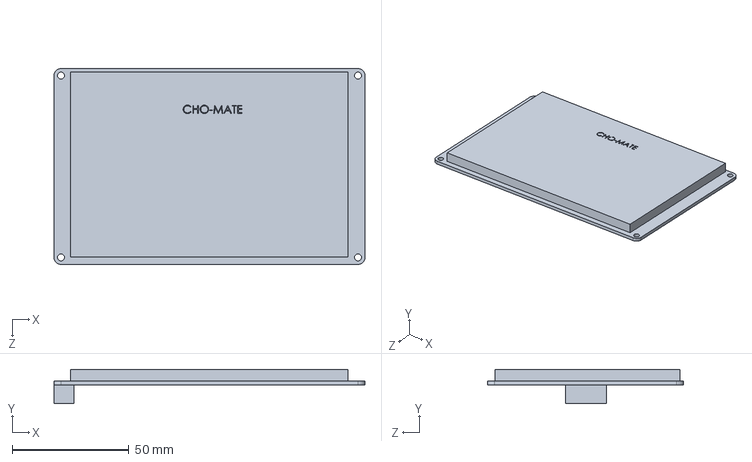
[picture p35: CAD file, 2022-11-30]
SolidWorks/Nextion 5inch display.SLDPRT
133.4 x 14.6 x 84.0 mm

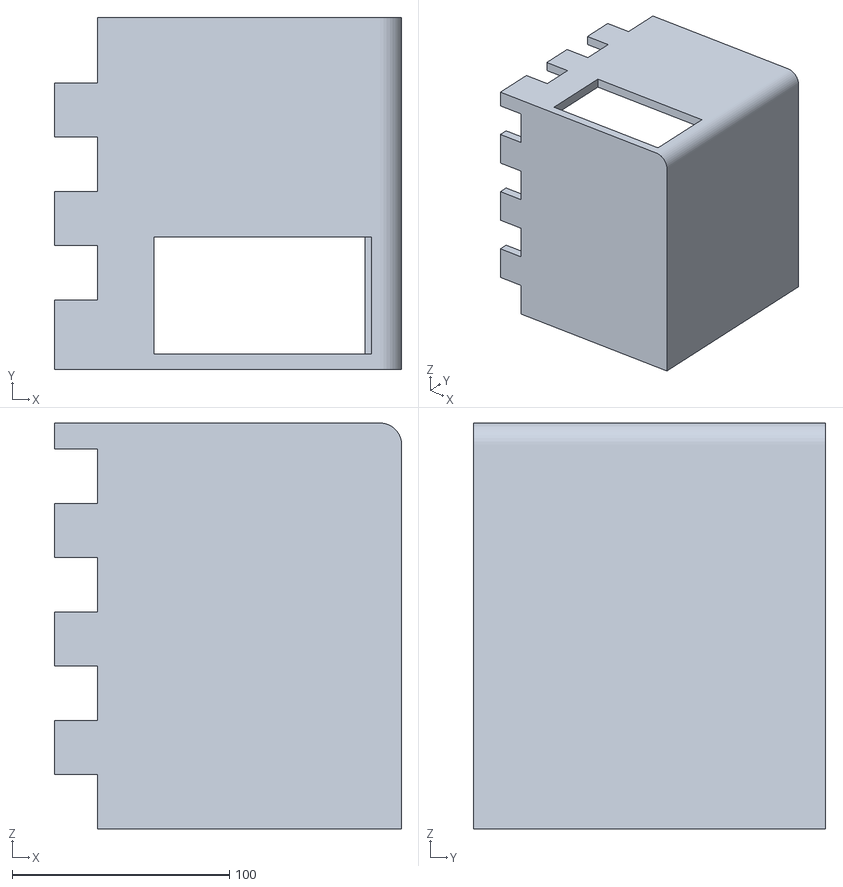
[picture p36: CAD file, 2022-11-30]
STL files/Housing_Left_Skittle_Side.STL
160.0 x 162.0 x 187.0

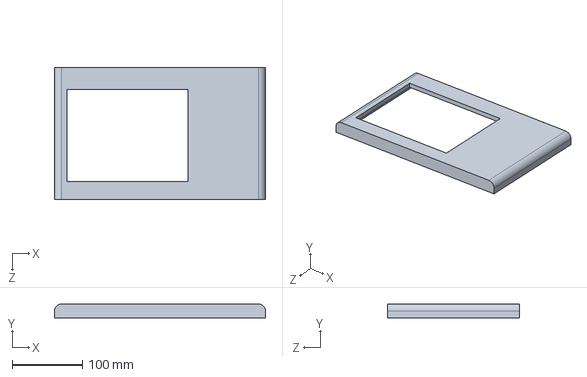
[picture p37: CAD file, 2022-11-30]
SolidWorks/Top.SLDPRT
300.0 x 20.0 x 187.0 mm

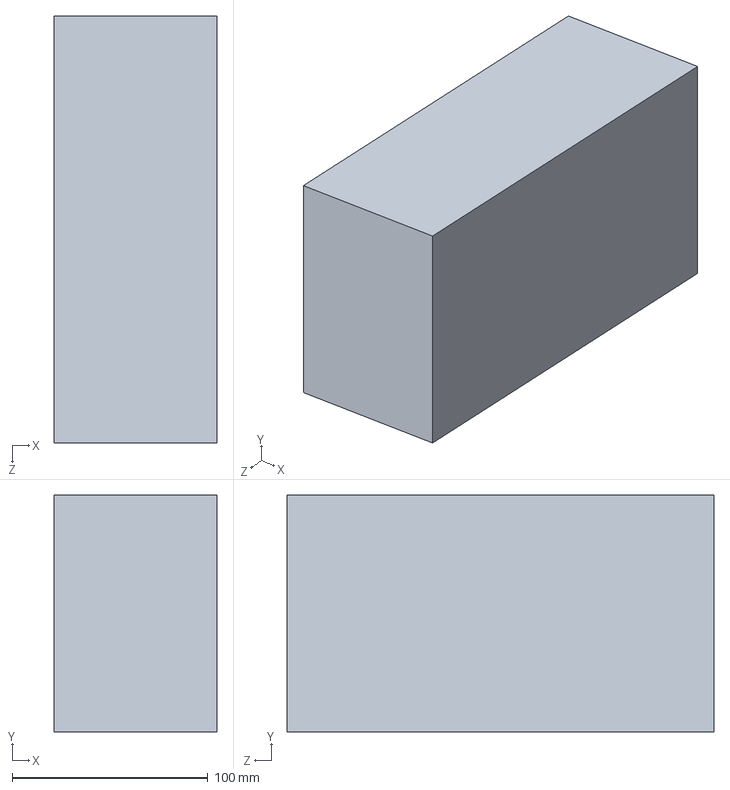
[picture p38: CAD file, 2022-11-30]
SolidWorks/Water bottle.SLDPRT
83.0 x 121.0 x 218.0 mm

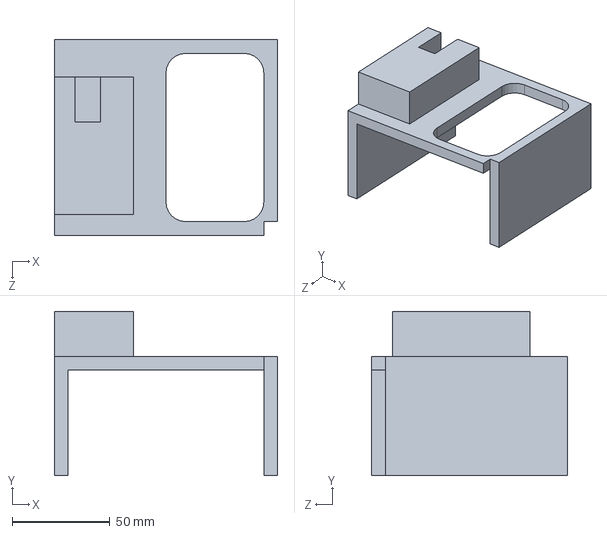
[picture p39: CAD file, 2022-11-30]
SolidWorks/power_supply_housing.SLDPRT
114.0 x 84.0 x 100.0 mm

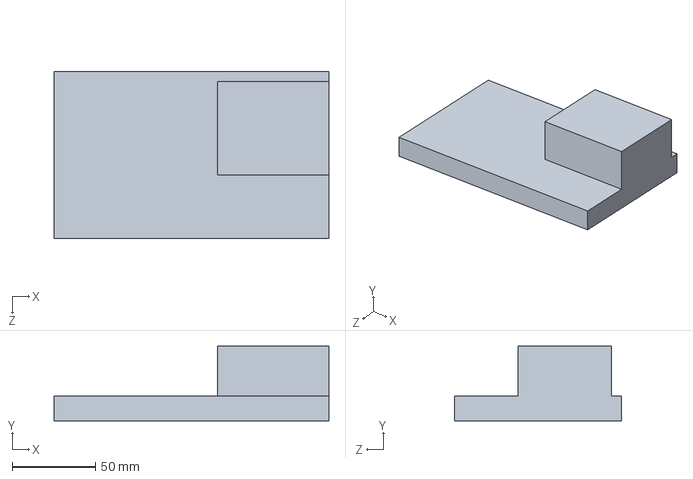
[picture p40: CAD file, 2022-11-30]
SolidWorks/psu.SLDPRT
165.0 x 45.0 x 100.0 mm

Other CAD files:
SolidWorks/dispenserv3.SLDPRT
SolidWorks/actuator_mount.SLDPRT
SolidWorks/pressure_sensor.SLDPRT
SolidWorks/Tray_bottom.SLDPRT
STL files/Tray_Top_Left.STL
STL files/Tray_Top_right.STL
STL files/Tray_bottom_Left.STL
STL files/Tray_bottom_right.STL
STL files/dispenserv3.STL
STL files/power_supply_housing.STL
STL files/updated_funnel.STL
SolidWorks/Back_updated.SLDPRT
SolidWorks/Back_updated_left.SLDPRT
SolidWorks/Bottom.SLDPRT
SolidWorks/Left.SLDPRT
SolidWorks/Right.SLDPRT
SolidWorks/Skittle Ramp.SLDPRT
SolidWorks/Skittle_container.SLDPRT
SolidWorks/Surge Protector.SLDPRT
SolidWorks/Tray insert.SLDPRT
SolidWorks/Tray.SLDPRT
SolidWorks/Tray_Top.SLDPRT
SolidWorks/Tray_Top.STL
SolidWorks/Tray_Top_Left.SLDPRT
SolidWorks/Tray_Top_right.SLDPRT
SolidWorks/Tray_bottom.STL
SolidWorks/Tray_bottom2.STL
SolidWorks/Tray_bottom_Left.SLDPRT
SolidWorks/Tray_bottom_right.SLDPRT
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

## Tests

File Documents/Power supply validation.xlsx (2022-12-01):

12V Amp | 12V out | 5V Amp | 5V out | 12V Amp at full 5V load | 12V out at full load
0 | 12.081 | 0 | 5.199 | 0 | 12.497
0.1 | 12.053 | 0.1 | 5.194 | 0.25 | 12.436
0.2 | 12.035 | 0.2 | 5.198 | 0.5 | 12.395
0.3 | 12.018 | 0.3 | 5.203 | 0.75 | 12.227
0.4 | 12.001 | 0.4 | 5.205 | 1 | 11.863
0.5 | 11.984 | 0.5 | 5.203 | 1.25 | 11.385
0.6 | 11.964 | 0.6 | 5.199 | 1.5 | 11.058
0.7 | 11.95 | 0.7 | 5.196
0.8 | 11.922 | 0.8 | 5.191
0.9 | 11.893 | 0.9 | 5.006
1 | 11.813 | 1 | 4.994
1.1 | 11.715 | 1.1 | 4.984
1.2 | 11.572 | 1.2 | 4.983
1.3 | 11.415
1.4 | 11.253
1.5 | 11.073

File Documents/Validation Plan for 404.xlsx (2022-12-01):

CHO-MATE Validation Steps | Success Criteria | Methodology | Status
Voltage out of 5V buck | Buck Converter gives the correct output voltage | Check Voltage in and out of 5V Buck Converter using E-load test | Pass
Voltage out of 12V buck | Buck Converter gives the correct output voltage | Check Voltage in and out of 12V Buck Converter using E-load test | Pass
System Casing Dimension Requirements | Casing is capable of holding all necessary components | Preplace all components within the casing before final mounting | Pass
Test Ultrasonic and Load Cell Sensors | Ultrasonic Sensor can measure a square area of 6x6 inches with 95% accuracy, Load Cell can measure mass within 95% accuracy compared to a kitchen scale | Test measurement at various levels - full, 3/4 full, half full, partially full, and empty - and report values, compare with actual values and prove that they meet the criteria | Pass
Validate the use of IRF730 MOSFETs for switching | IRF730 MOSFETs are adequate to handle the load of the solenoid for the skittle dispenser and the DC motor for the peristaltic pump | Test MOSFETs with Continuous current draw at 1x 1.5x and 2x the required load for both loads to ensure there is headroom incase of a short | Pass
Ensure Dispenser Code is up to standards | Code must not have runtime failures in edge cases such as overloaded mqtt callback messages or char arrays that cause heap errors and crash the ESP32 | Use GDB to track the ESP32 memory use during runtime of the program, test entire code functionality in a single run while monitoring resources and ensuring no defunct processes/watchdog timeouts. Ensure that Memory useage is well below 4MB limit | Pass
Nextion Display Integration and Power Draw | Display can accurately interface with ESP32 via Serial UART, power draw is acceptable | Test power draw of Nextion and ensure that it is within limits of Holden's Power Supply Headroom as listed on the Nextion specsheet, ensure that the Dispenser code does not miss Serial UART messages, may require implementation and testing of a listener process that runs permanently in the background | Pass
Test and Validate that the PCB performs and operates the same as the breadboarded circuit | PCB must correclty function and operate in the same manner as the design and the breadboard | Validate all traces are correct and then install components and test that all continuities are as expected. Power the PCB and validate that the dispenser is working as intended. | Pass
Notifications | Application can push notifications, and Dispenser is able to send various notifications like refill notifactions | Use Expo's built-in notification system to set up notifications, and use MQTT to schedule communication between the device and application for coordinating notifications | Pass
Information Screens | User can interact with more screens that display more information, such as a graph of glucose measurements in a week, a page that shows a range of dispensings, etc. | Use Expo and React functionality to pull information from the database and display it to the user in easy-to-understand graphs | Pass
Glucose Input System | User is able to input their current glucose level and the application will send it to the machine, which will then dispense the required amount | Implement basic glucose input, and utilize MQTT to communicate with machine on a new channel, sending glucose information | Pass
Notification and Application Backend | Notifications can be sent and received from the machine during any period | Utilize the Expo Push Notification API to send notifications unprompted to the application | Pass
Nextion Display UX | Users easily understand the Nextion display and UX is similar to application | Utilize the Nextion SDK and make custom design elements to make the display function well and be visually appealing | Pass
 |  |  |  | Ownership
 |  |  |  | Holden Haile
 |  |  |  | Abhi Singh
 |  |  |  | Kelton Chesshire

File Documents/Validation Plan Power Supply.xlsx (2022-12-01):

Schematic |  |  |  | Proto Board | Test | Expected outcome | Validation
5V Buck | Current(A) | Load(W) | Output(V) |  | Min Power load | Consistent supplied Voltage | Untested
 | 0.1 | 0.5 | 5.004 |  | Scaling Load Val | Constant Voltage supply | Untested
 | 0.5 | 2.5 | 5.003 |  | Over Loaded | Voltage Regulated | Untested
 | 1 | 5 | 5.002 |  | Transformer | AC Voltage stepdown | Untested
 | 1.5 | 7.5 | 5.001 |  | Rectifier | Voltage linearization | Untested
 | 2 | 10 | 5 |  | Input Capacitors | Voltage smoothing | Untested
 | 2.5 | 12.5 | 4.999
12V Buck | Current(A) | Load(W) | Output(V)
 | 0.1 | 1.2 | 12.003
 | 0.5 | 6 | 12
 | 1 | 12 | 11.995
 | 1.5 | 18 | 11.991
 | 2 | 24 | 11.987
 | 2.5 | 32 | 11.983
 | 3 | 36 | 11.979

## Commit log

2022-04-26 Changed grams to milliliters for liquid
2022-11-30 Create STL files
2022-11-30 Switched from local folder to remote repo that is updated
